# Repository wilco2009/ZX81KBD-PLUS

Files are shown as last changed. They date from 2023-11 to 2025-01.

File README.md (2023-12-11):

# ZX81KBD-PLUS
 Joystick, PS2 & USB keyboard interface for the ZX81
 
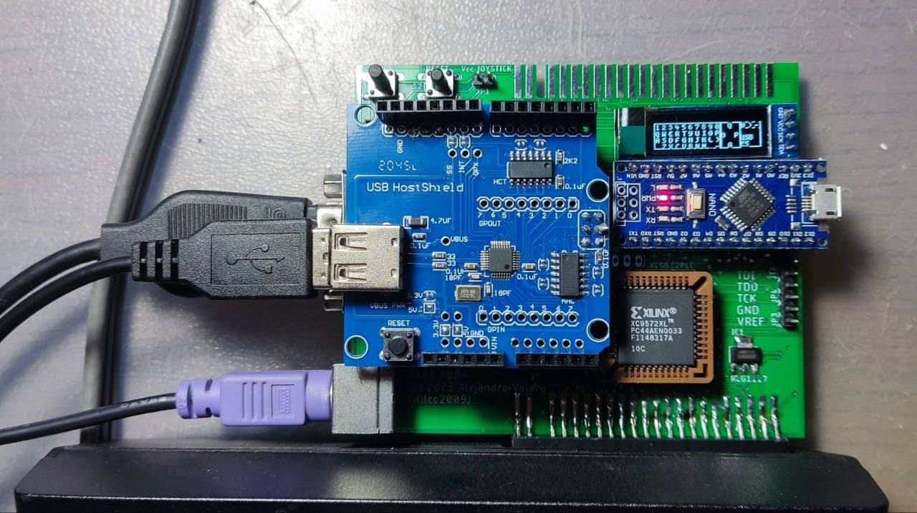
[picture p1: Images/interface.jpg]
 
 
 ## INTERFACE COMPONENTS
 
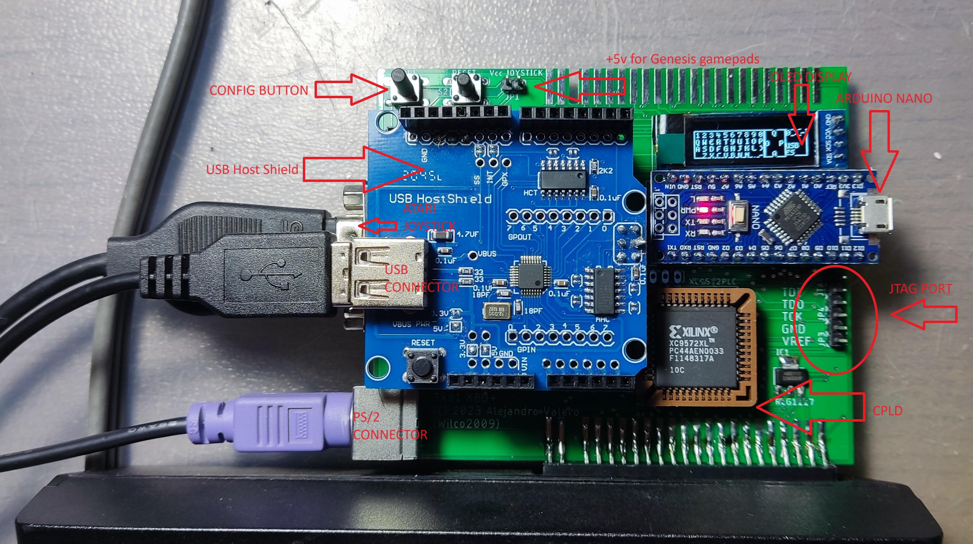
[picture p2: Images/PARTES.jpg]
 

 COMPONENT LIST
 |  Component |  Quantity |
 | ------| --------| 
 | Arduino nano R3	1
 | Push Button 6x6 | 2
 | DB9 male	| 1
 | Mini DIN	9 PIN | 1
 | PCF8574P	| 1
 | USB Host Shield	| 1
 | OLED 128x32 I2C	| 1
 | XC9572XL-PLCC44	| 1
 | LM1117 3v3 regulator SOT223| 1
 | Res 100K	| 2
 | Res 4K7	| 8
 | DIP16 socket	| 1
 | PLCC44 socket (Though hole)	| 1
 | pin header male 1x40 | 1
 | pin header male 1x40 (long pins)	| 1
 | pin header female 1x40	| 2
 | 74AHC125D SOP14	| 1
 | EDGE CONNECTOR | 1
 
Once the interface is assembled, the first thing we have to do is program the arduino (using the arduino IDE) or the avrdude.
We must also program the CPLD using the Xilinx IMPACT program and connecting a programming cable to the JTAG connector.

## REPLACING THE USB HOST SHIELD CHIP
Unless we buy an original USB Host Shield from the official Arduino store, it is very likely that we will end up with a defective board from Aliexpress. The Chinese manufacturers have not strictly followed the original scheme and have used a 74HC125D instead of a 74AHC125D indicated in the original scheme.

The good news is that by replacing this chip it is very likely that we will have a fully functional board, the bad news is that we will have to desolder the old chip and solder the new one.
In the photo you can see the chip that needs to be replaced.

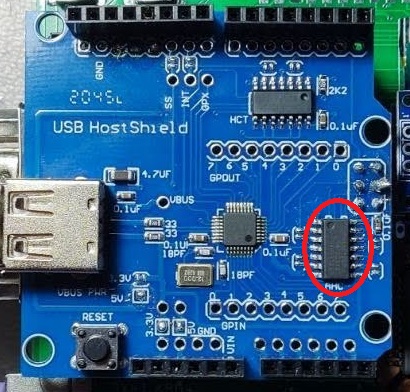
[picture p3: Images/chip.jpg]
 

## MAIN SCREEN

The main screen of the OLED display is divided into two sections.
On the left we have a representation of the zx81 keyboard, and on the right a representation of the joystick with its three buttons (A B and FIRE)
When you press any key on the keyboard or any button on the joystick we will see the pressure on the display.
Additionally, in the joystick section we can see which keys are configured for each of the joystick buttons.

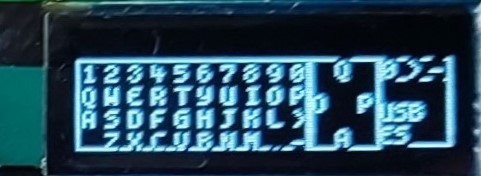
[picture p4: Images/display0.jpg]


## INTERFACE CONFIGURATION

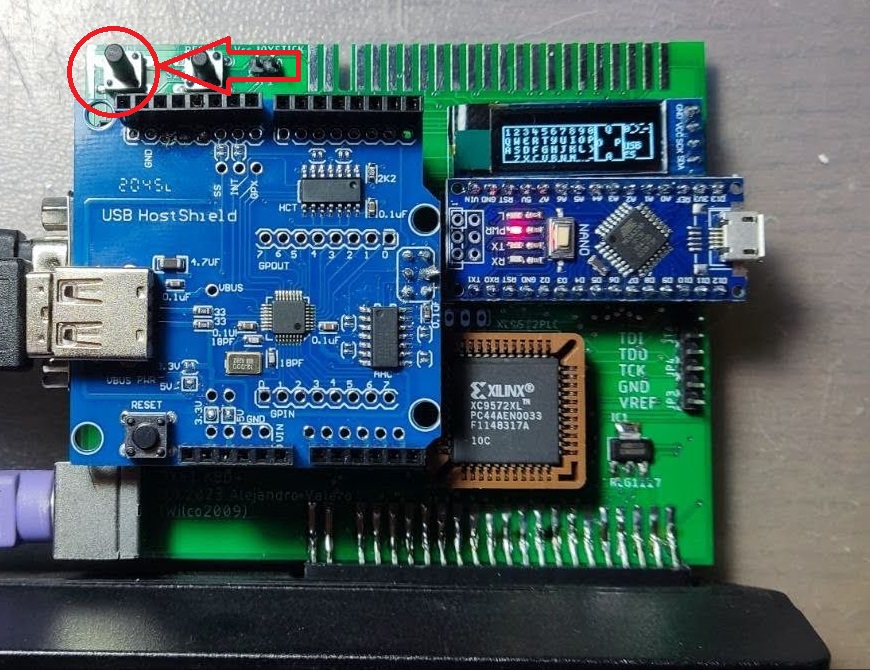
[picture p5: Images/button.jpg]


To enter the configuration menu we can do it in two ways:
- Pressing the configuration button
- Pressing F10 on the keyboard

Once inside the menu we can move through the options using the joystick or the keyboard cursor arrows. 
To select an option we will press the fire button on the joystick or the enter key on the keyboard.

### SELECTION OF KEYBOARD LAYOUT

The first option that appears when we access the menu is the one that will allow us to choose the keyboard layout.

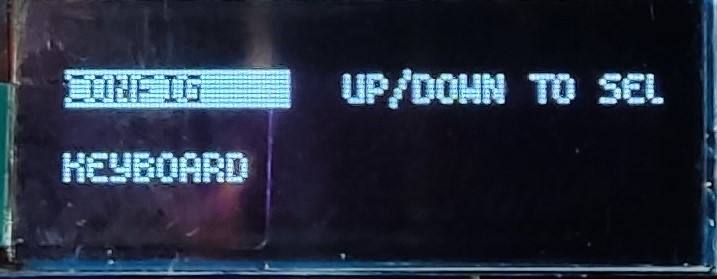
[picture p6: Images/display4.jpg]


The system is prepared for the following distributions:
- "US" - USA
- "UK" - United Kingdom
- "ES" - Spain
- "DE" - Germany

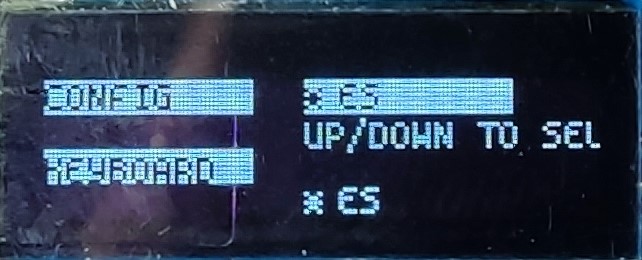
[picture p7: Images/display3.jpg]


The active keyboard will be marked with an asterisk.
We can change the active keyboard with the up/down arrows on the keyboard or joystick and select with enter or the fire button.
The ESC key will return to the main menu.

### REDEFINING JOYSTICK KEYS

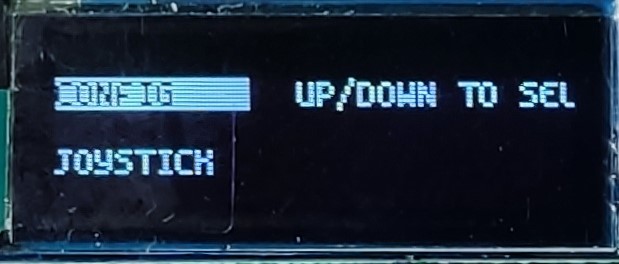
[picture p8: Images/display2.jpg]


To redefine the joystick keys we will select the second option from the main menu by moving down with the arrow and press enter/fire.
After this, a screen identical to the main screen will appear but with the first joystick button to be redefined (UP) flashing.
We will select the key we want with the arrows in the left section of the screen and press ENTER or fire.
We can also directly press the key that we want to assign, except in the case of the cursor and enter keys, which would have to be selected by the first method mentioned.
By pressing the ESC or A key on the joystick we will go to the next button without modifying the current one.

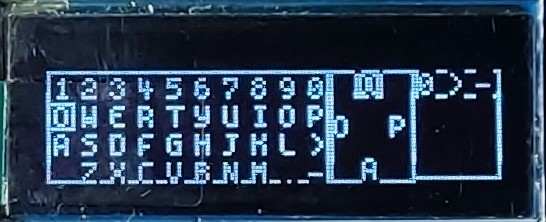
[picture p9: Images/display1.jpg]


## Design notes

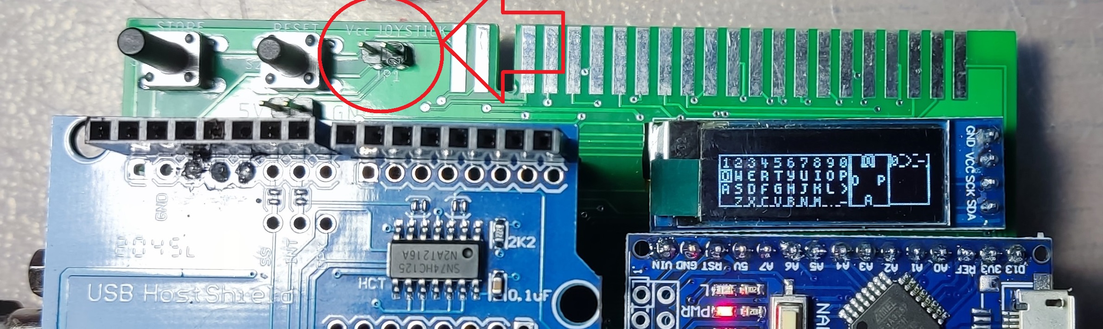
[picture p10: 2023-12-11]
Images/jumper.jpg

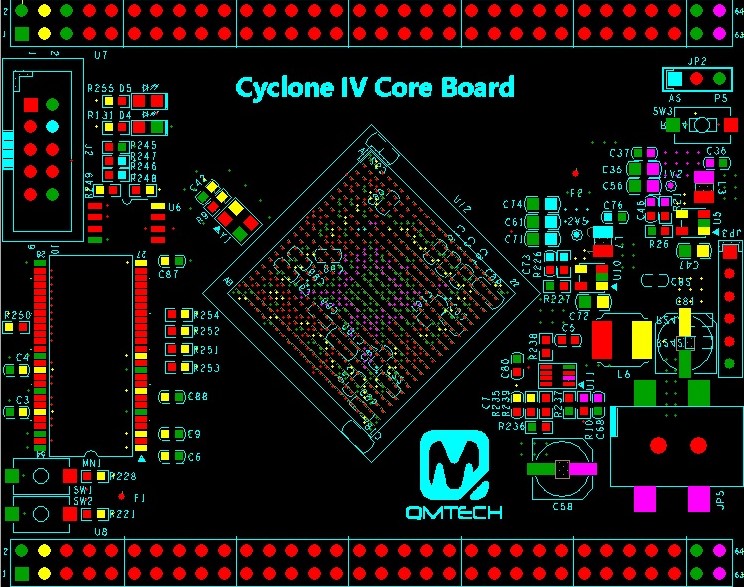
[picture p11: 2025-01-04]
Images/Dimension_V2.jpg

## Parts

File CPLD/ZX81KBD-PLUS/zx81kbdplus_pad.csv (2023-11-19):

Release 8.1i - Fit P.20131013
Copyright(c) 1995-2003 Xilinx Inc. All rights reserved
11-11-2023 1:36AM
NOTE: This file is designed to be imported into a spreadsheet program
such as Microsoft Excel for viewing | printing and sorting. The comma ' | '
character is used as the data field separator.
This file is also designed to support parsing.
Input file: zx81kbdplus.ngd
output file: zx81kbdplus_pad.csv
Part type: xc9572xl
Speed grade: -10
Package: pc44
Pinout by Pin Number:
----- | ----- | ----- | ----- | ----- | ----- | ----- | ----- | ----- | -----
Pin Number | Signal Name | Pin Usage | Pin Name | Direction | IO Standard | IO Bank Number | {blank} | Slew Rate | Termination | {blank} | Voltage | Constraint
P1 | C<0> | I | I/O | INPUT
P2 | CLK | I | I/O | INPUT
P3 | RST | I | I/O | INPUT
P4 | TIE |  | I/O
P5 | TIE |  | I/O/GCK1
P6 | TIE |  | I/O/GCK2
P7 | TIE |  | I/O/GCK3
P8 | TIE |  | I/O
P9 | TIE |  | I/O
P10 | GND |  | GND
P11 | TEST1 | O | I/O | OUTPUT
P12 | TEST2 | O | I/O | OUTPUT
P13 | TEST3 | O | I/O | OUTPUT
P14 | D<0> | O | I/O | OUTPUT
P15 | TDI |  | TDI
P16 | TMS |  | TMS
P17 | TCK |  | TCK
P18 | D<1> | O | I/O | OUTPUT
P19 | D<2> | O | I/O | OUTPUT
P20 | TIE |  | I/O
P21 | VCC |  | VCCINT
P22 | A0 | I | I/O | INPUT
P23 | GND |  | GND
P24 | TIE |  | I/O
P25 | D<3> | O | I/O | OUTPUT
P26 | D<4> | O | I/O | OUTPUT
P27 | A<15> | I | I/O | INPUT
P28 | A<14> | I | I/O | INPUT
P29 | A<13> | I | I/O | INPUT
P30 | TDO |  | TDO
P31 | GND |  | GND
P32 | VCC |  | VCCIO
P33 | A<12> | I | I/O | INPUT
P34 | nIORQ | I | I/O | INPUT
P35 | A<11> | I | I/O | INPUT
P36 | nRD | I | I/O | INPUT
P37 | A<10> | I | I/O | INPUT
P38 | A<9> | I | I/O | INPUT
P39 | A<8> | I | I/O/GSR | INPUT
P40 | C<4> | I | I/O/GTS2 | INPUT
P41 | VCC |  | VCCINT
P42 | C<3> | I | I/O/GTS1 | INPUT
P43 | C<2> | I | I/O | INPUT
P44 | C<1> | I | I/O | INPUT
To preserve the pinout above for future design iterations in
Project Navigator simply execute the (Lock Pins) process
located under the (Implement Design) process in a toolbox named
(Optional Implementation Tools) or invoke PIN2UCF from the
command line. The location constraints will be written into your
specified UCF file

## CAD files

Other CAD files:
CPLD/ZX81KBD-PLUS/isim/zx81kbdtb_isim_beh.exe.sim/work/zx81kbdtb_isim_beh.exe_main.nt.obj
CPLD/ZX81KBD-PLUS/isim/zx81kbdtb_isim_beh.exe.sim/work/m_00000000002093604177_0389357912.nt.obj
CPLD/ZX81KBD-PLUS/isim/zx81kbdtb_isim_beh.exe.sim/work/m_00000000002113335398_0986573990.nt.obj
CPLD/ZX81KBD-PLUS/isim/zx81kbdtb_isim_beh.exe.sim/work/m_00000000004134447467_2073120511.nt.obj

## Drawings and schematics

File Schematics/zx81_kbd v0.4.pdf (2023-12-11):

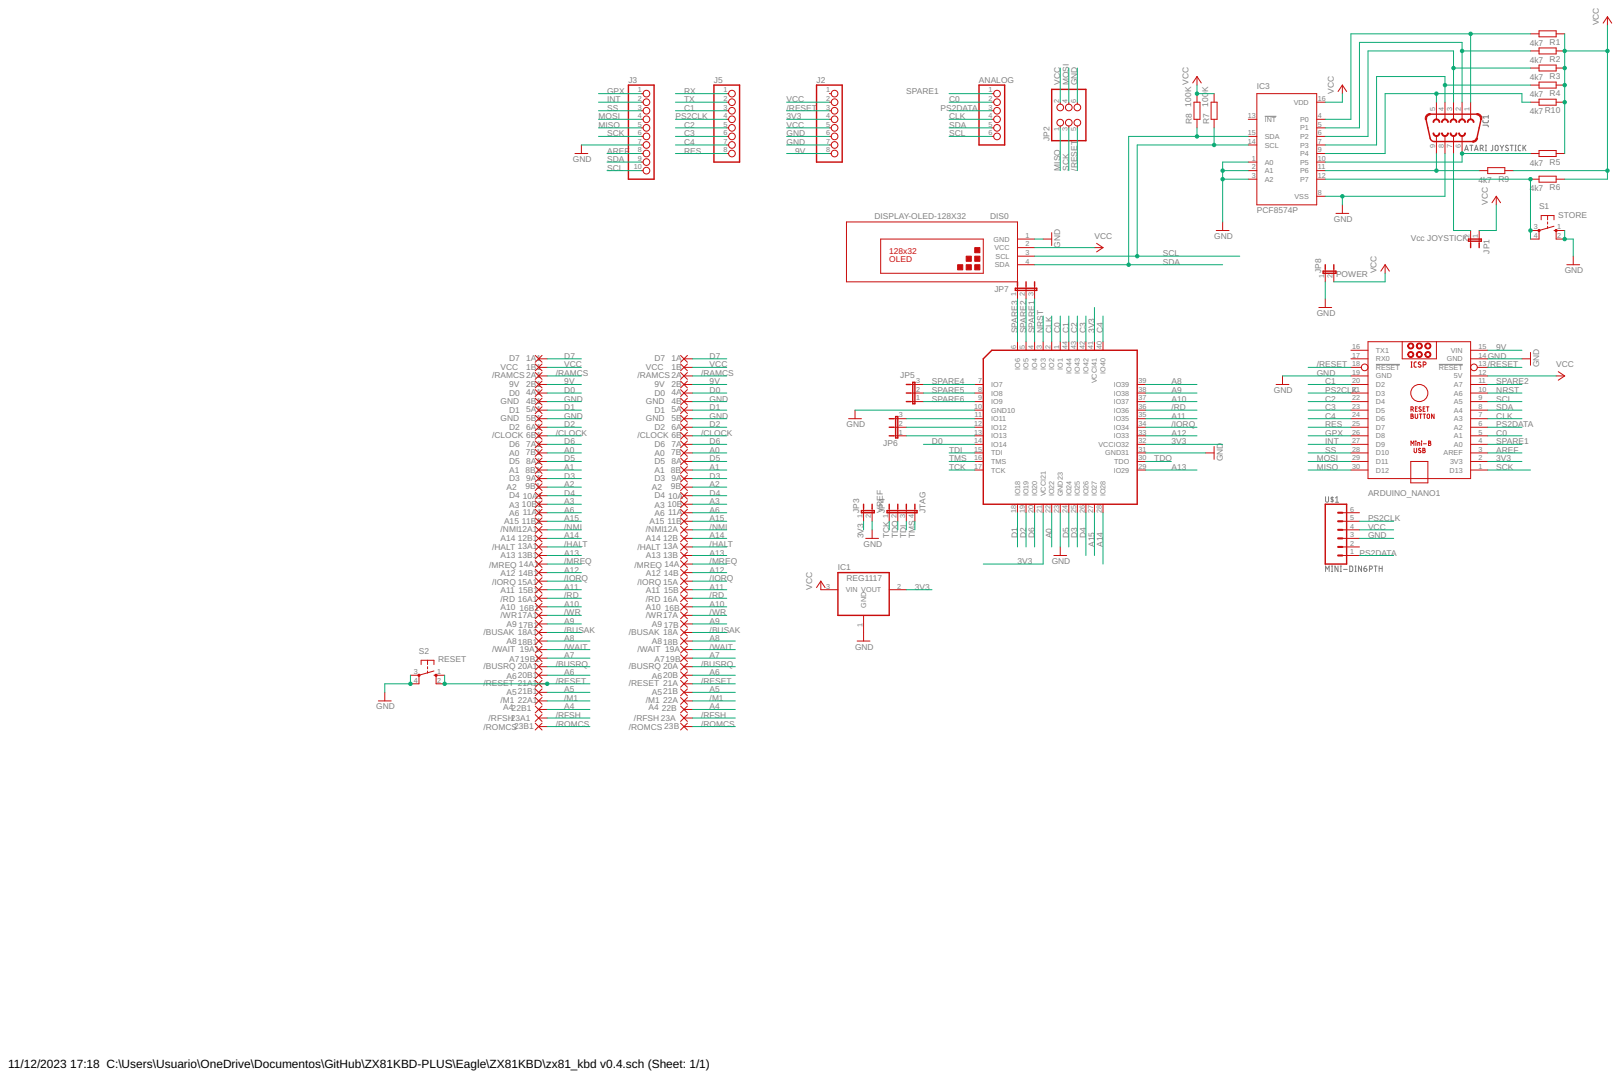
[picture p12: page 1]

11/12/2023 17:18 C:\Users\Usuario\OneDrive\Documentos\GitHub\ZX81KBD-PLUS\Eagle\ZX81KBD\zx81_kbd v0.4.sch (Sheet: 1/1)

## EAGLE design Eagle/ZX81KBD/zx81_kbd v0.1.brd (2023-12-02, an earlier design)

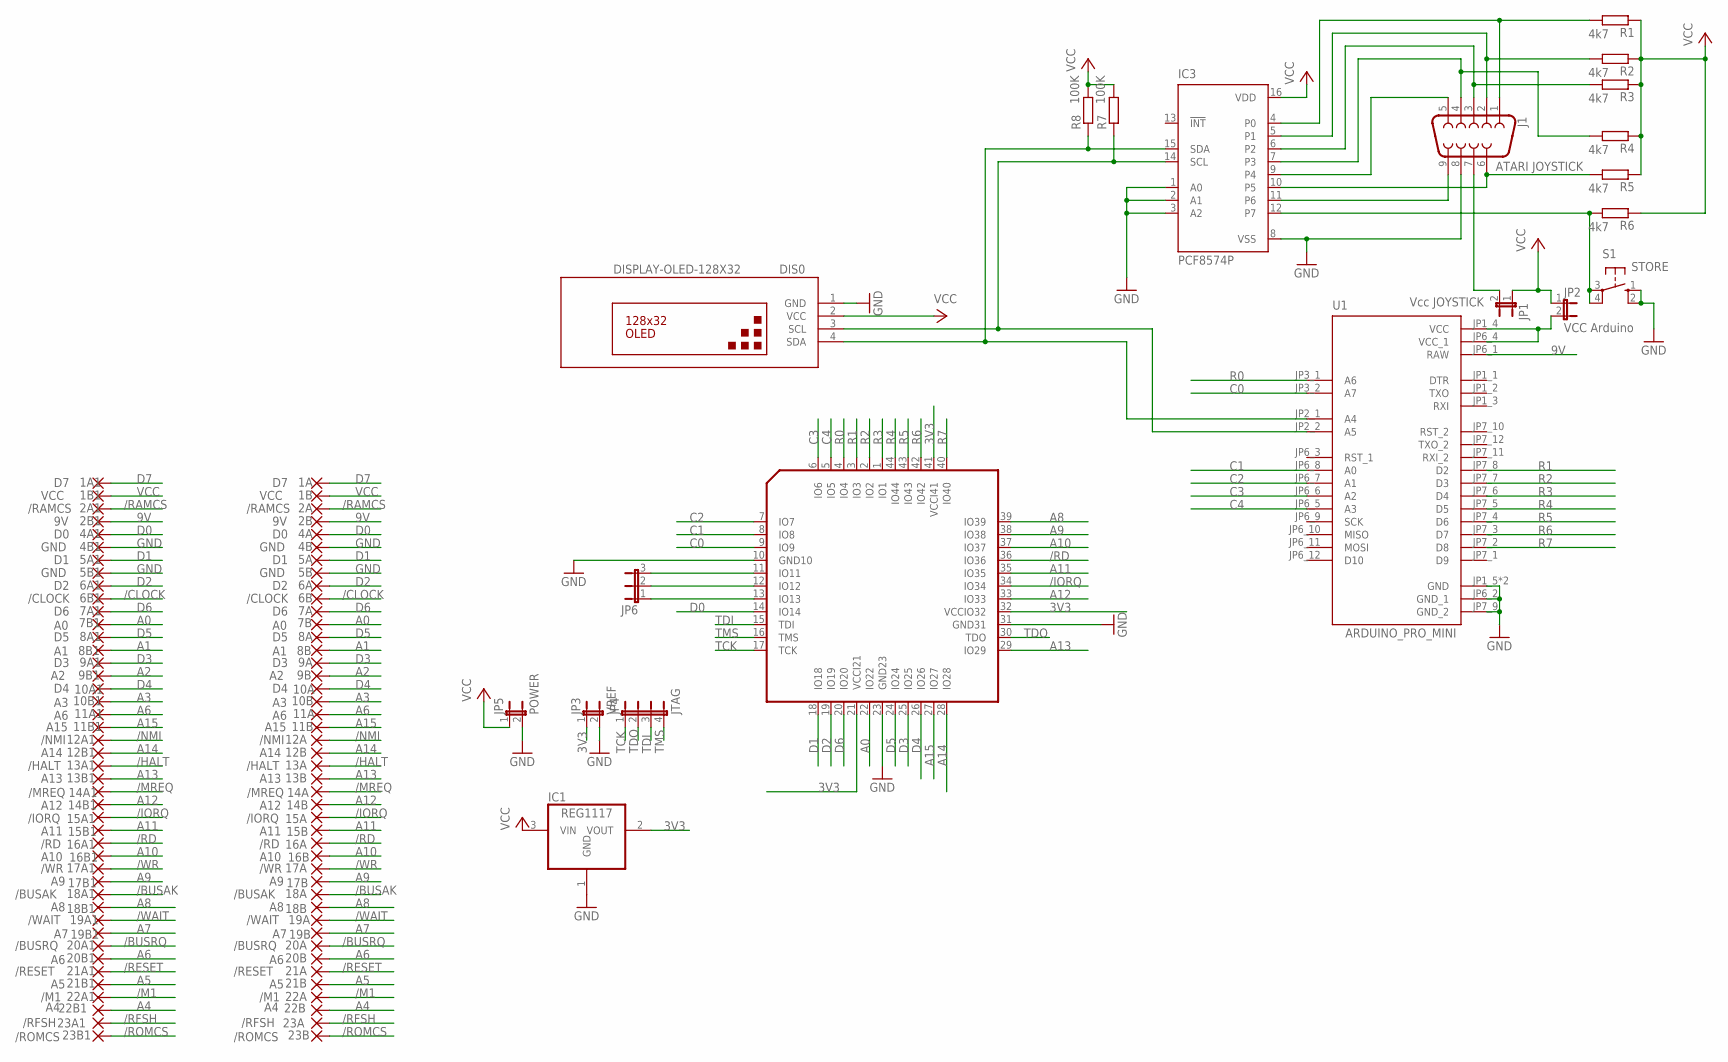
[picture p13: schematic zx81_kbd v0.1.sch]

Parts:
1A, 1A1: D7; EDGEPIN
1B, 1B1: VCC; EDGEPIN
2A, 2A1: /RAMCS; EDGEPIN
2B, 2B1: 9V; EDGEPIN
4A, 4A1: D0; EDGEPIN
4B, 4B1, 5B, 5B1: GND; EDGEPIN
5A, 5A1: D1; EDGEPIN
6A, 6A1: D2; EDGEPIN
6B, 6B1: /CLOCK; EDGEPIN
7A, 7A1: D6; EDGEPIN
7B, 7B1: A0; EDGEPIN
8A, 8A1: D5; EDGEPIN
8B, 8B1: A1; EDGEPIN
9A, 9A1: D3; EDGEPIN
9B, 9B1: A2; EDGEPIN
10A, 10A1: D4; EDGEPIN
10B, 10B1: A3; EDGEPIN
11A, 11A1, 20B, 20B1: A6; EDGEPIN
11B, 11B1: A15; EDGEPIN
12A, 12A1: /NMI; EDGEPIN
12B, 12B1: A14; EDGEPIN
13A, 13A1: /HALT; EDGEPIN
13B, 13B1: A13; EDGEPIN
14A, 14A1: /MREQ; EDGEPIN
14B, 14B1: A12; EDGEPIN
15A, 15A1: /IORQ; EDGEPIN
15B, 15B1: A11; EDGEPIN
16A, 16A1: /RD; EDGEPIN
16B, 16B1: A10; EDGEPIN
17A, 17A1: /WR; EDGEPIN
17B, 17B1: A9; EDGEPIN
18A, 18A1: /BUSAK; EDGEPIN
18B, 18B1: A8; EDGEPIN
19A, 19A1: /WAIT; EDGEPIN
19B, 19B1: A7; EDGEPIN
20A, 20A1: /BUSRQ; EDGEPIN
21A, 21A1: /RESET; EDGEPIN
21B, 21B1: A5; EDGEPIN
22A, 22A1: /M1; EDGEPIN
22B, 22B1: A4; EDGEPIN
23A, 23A1: /RFSH; EDGEPIN
23B, 23B1: /ROMCS; EDGEPIN
DIS0: DISPLAY-OLED-128X32
IC1: REG1117; SOT223
IC3: PCF8574P; DIL16
J1: ATARI JOYSTICK; DB9_MALE
JP1: Vcc JOYSTICK; JP1
JP2: VCC Arduino; JP1
JP3: VREF; JP1
JP4: JTAG; JP4
JP5: POWER; JP1
JP6: JP2E; JP2
R1, R2, R3, R4, R5, R6: 4k7; 0204/7
R7, R8: 100K; 0204/7
S1: STORE; B3F-10XX_11MM
U1: ARDUINO_PRO_MINI; MODULE_ARDUINO_PRO_MINI
XC95CPLD: XC9572PLC; 3M44

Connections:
3V3: IC1.2 (VOUT), JP3.1, XC95CPLD.21 (VCCI21), XC95CPLD.32 (VCCIO32), XC95CPLD.41 (VCCI41)
9V: 2B.1, 2B1.1, U1.JP6_1 (RAW)
/BUSAK: 18A.1, 18A1.1
/BUSRQ: 20A.1, 20A1.1
/CLOCK: 6B.1, 6B1.1
/HALT: 13A.1, 13A1.1
/IORQ: 15A.1, 15A1.1, XC95CPLD.34 (IO34)
/M1: 22A.1, 22A1.1
/MREQ: 14A.1, 14A1.1
/NMI: 12A.1, 12A1.1
/RAMCS: 2A.1, 2A1.1
/RD: 16A.1, 16A1.1, XC95CPLD.36 (IO36)
/RESET: 21A.1, 21A1.1
/RFSH: 23A.1, 23A1.1
/ROMCS: 23B.1, 23B1.1
/WAIT: 19A.1, 19A1.1
/WR: 17A.1, 17A1.1
A0: 7B.1, 7B1.1, XC95CPLD.22 (IO22)
A1: 8B.1, 8B1.1
A2: 9B.1, 9B1.1
A3: 10B.1, 10B1.1
A4: 22B.1, 22B1.1
A5: 21B.1, 21B1.1
A6: 11A.1, 11A1.1, 20B.1, 20B1.1
A7: 19B.1, 19B1.1
A8: 18B.1, 18B1.1, XC95CPLD.39 (IO39)
A9: 17B.1, 17B1.1, XC95CPLD.38 (IO38)
A10: 16B.1, 16B1.1, XC95CPLD.37 (IO37)
A11: 15B.1, 15B1.1, XC95CPLD.35 (IO35)
A12: 14B.1, 14B1.1, XC95CPLD.33 (IO33)
A13: 13B.1, 13B1.1, XC95CPLD.29 (IO29)
A14: 12B.1, 12B1.1, XC95CPLD.28 (IO28)
A15: 11B.1, 11B1.1, XC95CPLD.27 (IO27)
C0: U1.JP3_2 (A7), XC95CPLD.9 (IO9)
C1: U1.JP6_8 (A0), XC95CPLD.8 (IO8)
C2: U1.JP6_7 (A1), XC95CPLD.7 (IO7)
C3: U1.JP6_6 (A2), XC95CPLD.6 (IO6)
C4: U1.JP6_5 (A3), XC95CPLD.5 (IO5)
D0: 4A.1, 4A1.1, XC95CPLD.14 (IO14)
D1: 5A.1, 5A1.1, XC95CPLD.18 (IO18)
D2: 6A.1, 6A1.1, XC95CPLD.19 (IO19)
D3: 9A.1, 9A1.1, XC95CPLD.25 (IO25)
D4: 10A.1, 10A1.1, XC95CPLD.26 (IO26)
D5: 8A.1, 8A1.1, XC95CPLD.24 (IO24)
D6: 7A.1, 7A1.1, XC95CPLD.20 (IO20)
D7: 1A.1, 1A1.1
GND: 4B.1, 4B1.1, 5B.1, 5B1.1, DIS0.1 (GND), IC1.1 (GND), IC3.1 (A0), IC3.2 (A1), IC3.3 (A2), IC3.8 (VSS), J1.8, JP3.2, JP5.2, S1.1 (S), S1.2 (S1), U1.JP1_5 (GND), U1.JP1_6 (GND), U1.JP6_2 (GND_1), U1.JP7_9 (GND_2), XC95CPLD.10 (GND10), XC95CPLD.23 (GND23), XC95CPLD.31 (GND31)
unnamed: JP6.3, XC95CPLD.11 (IO11)
unnamed: JP6.2, XC95CPLD.12 (IO12)
unnamed: JP6.1, XC95CPLD.13 (IO13)
unnamed: JP2.2, U1.JP1_4 (VCC), U1.JP6_4 (VCC_1)
unnamed: DIS0.4 (SDA), IC3.15 (SDA), R8.1, U1.JP2_1 (A4)
unnamed: DIS0.3 (SCL), IC3.14 (SCL), R7.1, U1.JP2_2 (A5)
unnamed: IC3.4 (P0), J1.1, R1.2
unnamed: IC3.5 (P1), J1.2, R2.2
unnamed: IC3.6 (P2), J1.3, R3.2
unnamed: IC3.7 (P3), J1.4, R4.2
unnamed: IC3.10 (P5), J1.6, R5.2
unnamed: IC3.9 (P4), J1.5
unnamed: IC3.12 (P7), R6.2, S1.3, S1.4 (P1)
unnamed: J1.7, JP1.2
unnamed: IC3.11 (P6), J1.9
R0: U1.JP3_1 (A6), XC95CPLD.4 (IO4)
R1: U1.JP7_8 (D2), XC95CPLD.3 (IO3)
R2: U1.JP7_7 (D3), XC95CPLD.2 (IO2)
R3: U1.JP7_6 (D4), XC95CPLD.1 (IO1)
R4: U1.JP7_5 (D5), XC95CPLD.44 (IO44)
R5: U1.JP7_4 (D6), XC95CPLD.43 (IO43)
R6: U1.JP7_3 (D7), XC95CPLD.42 (IO42)
R7: U1.JP7_2 (D8), XC95CPLD.40 (IO40)
TCK: JP4.1, XC95CPLD.17 (TCK)
TDI: JP4.3, XC95CPLD.15 (TDI)
TDO: JP4.2, XC95CPLD.30 (TDO)
TMS: JP4.4, XC95CPLD.16 (TMS)
VCC: 1B.1, 1B1.1, DIS0.2 (VCC), IC1.3 (VIN), IC3.16 (VDD), JP1.1, JP2.1, JP5.1, R1.1, R2.1, R3.1, R4.1, R5.1, R6.1, R7.2, R8.2

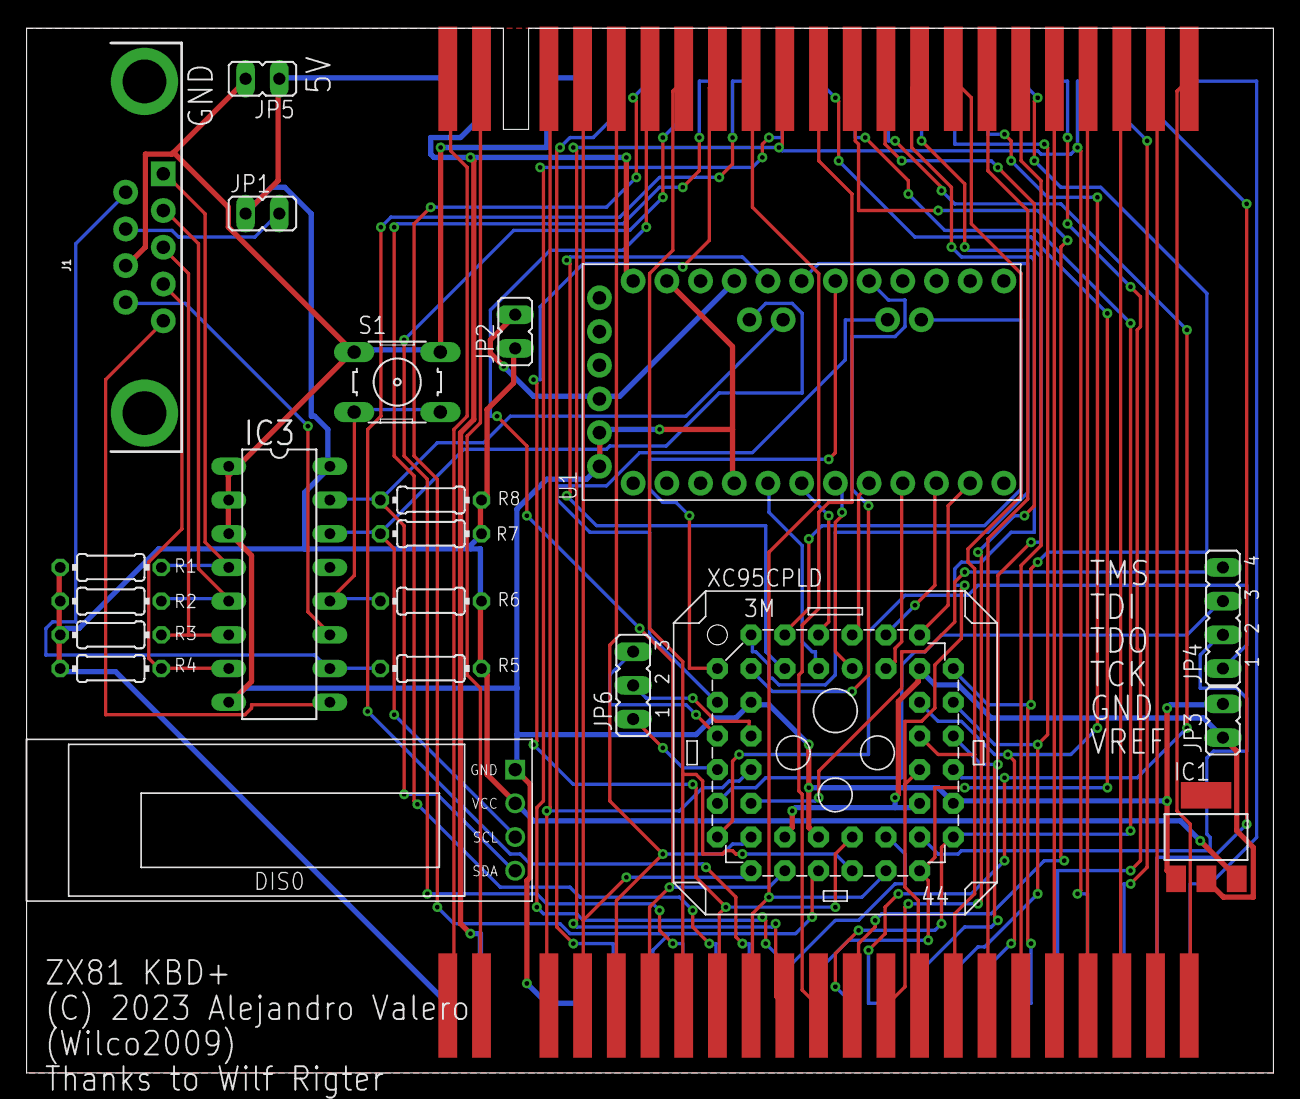
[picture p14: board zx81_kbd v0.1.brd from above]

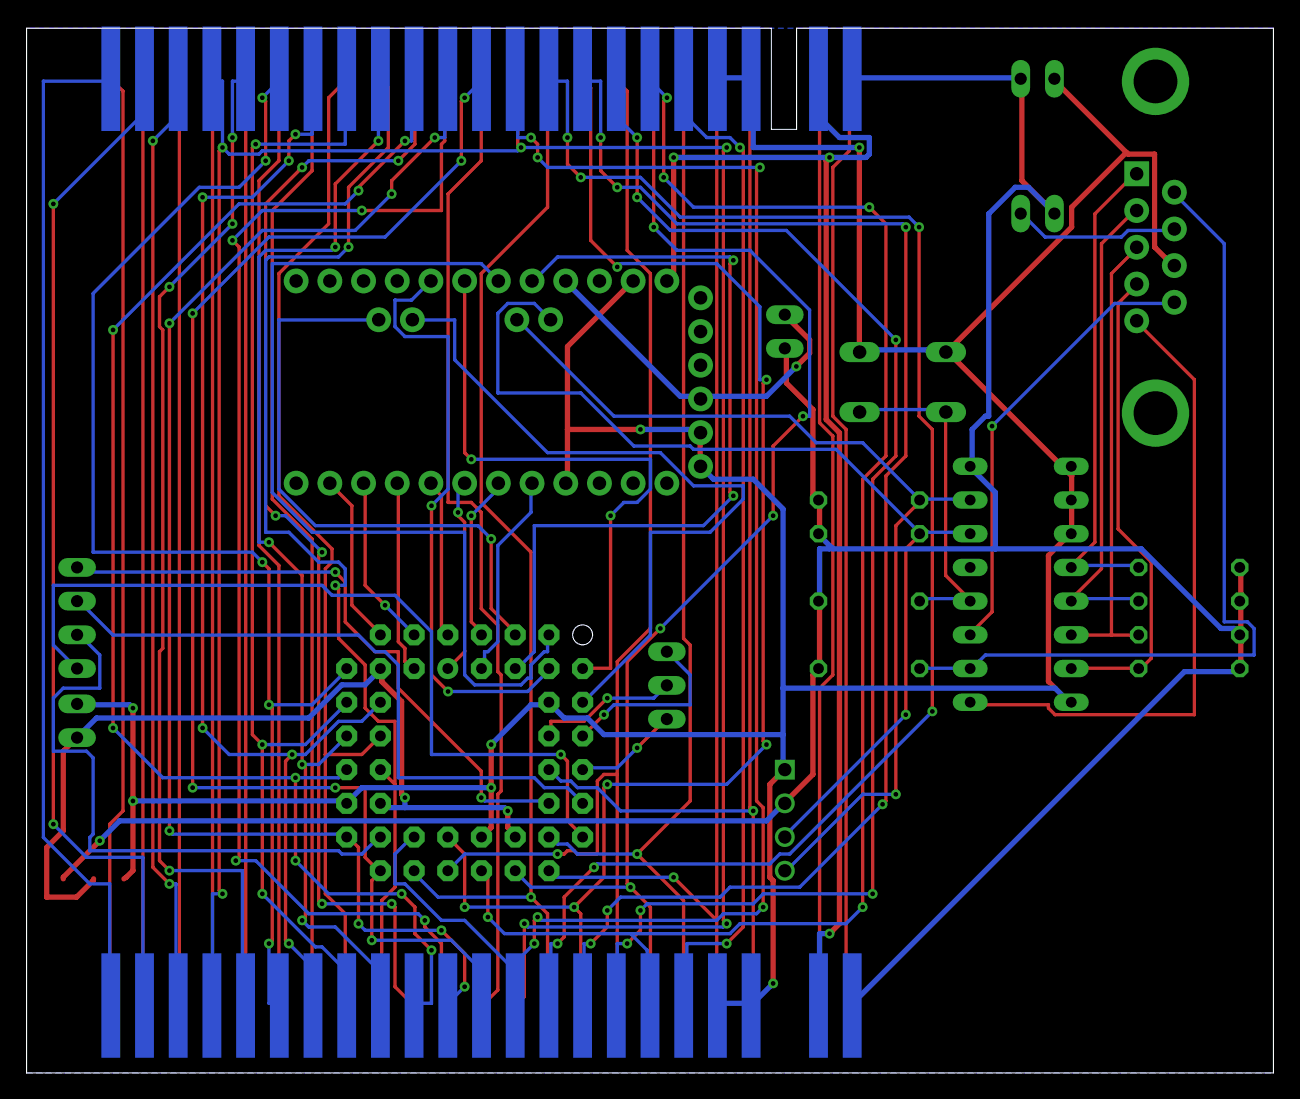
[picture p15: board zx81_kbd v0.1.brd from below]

Board: 2 copper layers, 94.0 x 78.7 mm, 109 parts (44 on the bottom side), 75 nets.

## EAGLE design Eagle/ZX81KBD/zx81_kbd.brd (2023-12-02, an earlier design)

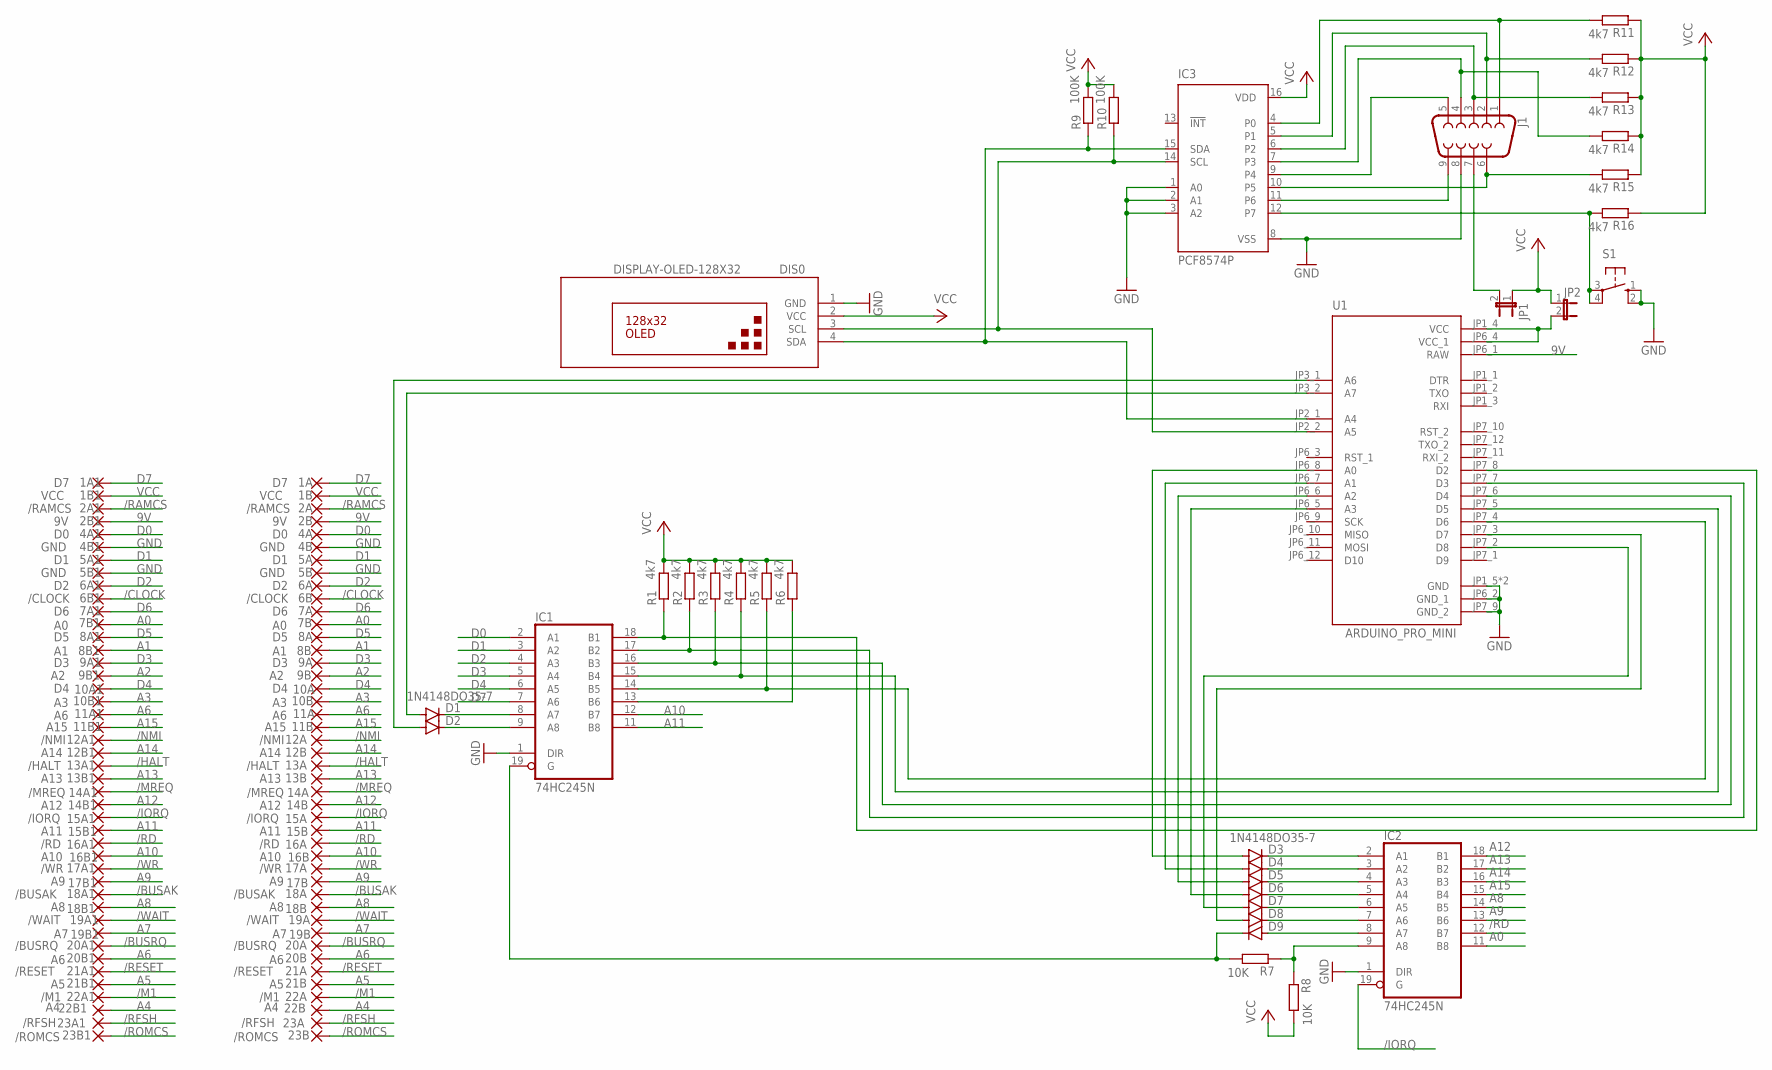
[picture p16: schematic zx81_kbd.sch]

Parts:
1A, 1A1: D7; EDGEPIN
1B, 1B1: VCC; EDGEPIN
2A, 2A1: /RAMCS; EDGEPIN
2B, 2B1: 9V; EDGEPIN
4A, 4A1: D0; EDGEPIN
4B, 4B1, 5B, 5B1: GND; EDGEPIN
5A, 5A1: D1; EDGEPIN
6A, 6A1: D2; EDGEPIN
6B, 6B1: /CLOCK; EDGEPIN
7A, 7A1: D6; EDGEPIN
7B, 7B1: A0; EDGEPIN
8A, 8A1: D5; EDGEPIN
8B, 8B1: A1; EDGEPIN
9A, 9A1: D3; EDGEPIN
9B, 9B1: A2; EDGEPIN
10A, 10A1: D4; EDGEPIN
10B, 10B1: A3; EDGEPIN
11A, 11A1, 20B, 20B1: A6; EDGEPIN
11B, 11B1: A15; EDGEPIN
12A, 12A1: /NMI; EDGEPIN
12B, 12B1: A14; EDGEPIN
13A, 13A1: /HALT; EDGEPIN
13B, 13B1: A13; EDGEPIN
14A, 14A1: /MREQ; EDGEPIN
14B, 14B1: A12; EDGEPIN
15A, 15A1: /IORQ; EDGEPIN
15B, 15B1: A11; EDGEPIN
16A, 16A1: /RD; EDGEPIN
16B, 16B1: A10; EDGEPIN
17A, 17A1: /WR; EDGEPIN
17B, 17B1: A9; EDGEPIN
18A, 18A1: /BUSAK; EDGEPIN
18B, 18B1: A8; EDGEPIN
19A, 19A1: /WAIT; EDGEPIN
19B, 19B1: A7; EDGEPIN
20A, 20A1: /BUSRQ; EDGEPIN
21A, 21A1: /RESET; EDGEPIN
21B, 21B1: A5; EDGEPIN
22A, 22A1: /M1; EDGEPIN
22B, 22B1: A4; EDGEPIN
23A, 23A1: /RFSH; EDGEPIN
23B, 23B1: /ROMCS; EDGEPIN
D1, D2, D3, D4, D5, D6, D7, D8, D9: 1N4148DO35-7; DO35-7
DIS0: DISPLAY-OLED-128X32
IC1, IC2: 74HC245N; DIL20
IC3: PCF8574P; DIL16
J1: DB9MALE; DB9_MALE
JP1, JP2: JP1E; JP1
R1, R2, R3, R4, R5, R6, R11, R12, R13, R14, R15, R16: 4k7; 0204/7
R7, R8: 10K; 0204/7
R9, R10: 100K; 0204/7
S1: 10-XX11MM; B3F-10XX_11MM
U1: ARDUINO_PRO_MINI; MODULE_ARDUINO_PRO_MINI

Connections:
9V: 2B.1, 2B1.1, U1.JP6_1 (RAW)
/BUSAK: 18A.1, 18A1.1
/BUSRQ: 20A.1, 20A1.1
/CLOCK: 6B.1, 6B1.1
/HALT: 13A.1, 13A1.1
/IORQ: 15A.1, 15A1.1, IC2.19 (G)
/M1: 22A.1, 22A1.1
/MREQ: 14A.1, 14A1.1
/NMI: 12A.1, 12A1.1
/RAMCS: 2A.1, 2A1.1
/RD: 16A.1, 16A1.1, IC2.12 (B7)
/RESET: 21A.1, 21A1.1
/RFSH: 23A.1, 23A1.1
/ROMCS: 23B.1, 23B1.1
/WAIT: 19A.1, 19A1.1
/WR: 17A.1, 17A1.1
A0: 7B.1, 7B1.1, IC2.11 (B8)
A1: 8B.1, 8B1.1
A2: 9B.1, 9B1.1
A3: 10B.1, 10B1.1
A4: 22B.1, 22B1.1
A5: 21B.1, 21B1.1
A6: 11A.1, 11A1.1, 20B.1, 20B1.1
A7: 19B.1, 19B1.1
A8: 18B.1, 18B1.1, IC2.14 (B5)
A9: 17B.1, 17B1.1, IC2.13 (B6)
A10: 16B.1, 16B1.1, IC1.12 (B7)
A11: 15B.1, 15B1.1, IC1.11 (B8)
A12: 14B.1, 14B1.1, IC2.18 (B1)
A13: 13B.1, 13B1.1, IC2.17 (B2)
A14: 12B.1, 12B1.1, IC2.16 (B3)
A15: 11B.1, 11B1.1, IC2.15 (B4)
D0: 4A.1, 4A1.1, IC1.2 (A1)
D1: 5A.1, 5A1.1, IC1.3 (A2)
D2: 6A.1, 6A1.1, IC1.4 (A3)
D3: 9A.1, 9A1.1, IC1.5 (A4)
D4: 10A.1, 10A1.1, IC1.6 (A5)
D5: 8A.1, 8A1.1
D6: 7A.1, 7A1.1
D7: 1A.1, 1A1.1, IC1.7 (A6)
GND: 4B.1, 4B1.1, 5B.1, 5B1.1, DIS0.1 (GND), IC1.1 (DIR), IC1.10 (GND), IC2.1 (DIR), IC2.10 (GND), IC3.1 (A0), IC3.2 (A1), IC3.3 (A2), IC3.8 (VSS), J1.8, S1.1 (S), S1.2 (S1), U1.JP1_5 (GND), U1.JP1_6 (GND), U1.JP6_2 (GND_1), U1.JP7_9 (GND_2)
unnamed: D3.C, IC2.2 (A1)
unnamed: IC1.18 (B1), R1.1, U1.JP7_8 (D2)
unnamed: IC1.17 (B2), R2.1, U1.JP7_7 (D3)
unnamed: IC1.16 (B3), R3.1, U1.JP7_6 (D4)
unnamed: JP2.2, U1.JP1_4 (VCC), U1.JP6_4 (VCC_1)
unnamed: IC1.14 (B5), R5.1, U1.JP7_4 (D6)
unnamed: IC1.13 (B6), R6.1
unnamed: D4.C, IC2.3 (A2)
unnamed: D5.C, IC2.4 (A3)
unnamed: D6.C, IC2.5 (A4)
unnamed: D7.C, IC2.6 (A5)
unnamed: D8.C, IC2.7 (A6)
unnamed: D9.A, IC2.8 (A7)
unnamed: IC2.9 (A8), R7.1, R8.1
unnamed: D1.A, U1.JP3_2 (A7)
unnamed: D1.C, IC1.8 (A7)
unnamed: D2.C, IC1.9 (A8)
unnamed: D9.C, IC1.19 (G), R7.2
unnamed: D2.A, U1.JP3_1 (A6)
unnamed: DIS0.4 (SDA), IC3.15 (SDA), R9.1, U1.JP2_1 (A4)
unnamed: DIS0.3 (SCL), IC3.14 (SCL), R10.1, U1.JP2_2 (A5)
unnamed: D6.A, U1.JP6_5 (A3)
unnamed: D5.A, U1.JP6_6 (A2)
unnamed: D4.A, U1.JP6_7 (A1)
unnamed: D7.A, U1.JP7_2 (D8)
unnamed: D8.A, U1.JP7_3 (D7)
unnamed: IC3.4 (P0), J1.1, R11.2
unnamed: IC1.15 (B4), R4.1, U1.JP7_5 (D5)
unnamed: D3.A, U1.JP6_8 (A0)
unnamed: IC3.5 (P1), J1.2, R12.2
unnamed: IC3.6 (P2), J1.3, R13.2
unnamed: IC3.7 (P3), J1.4, R14.2
unnamed: IC3.10 (P5), J1.6, R15.2
unnamed: IC3.9 (P4), J1.5
unnamed: IC3.12 (P7), R16.2, S1.3, S1.4 (P1)
unnamed: J1.7, JP1.2
unnamed: IC3.11 (P6), J1.9
VCC: 1B.1, 1B1.1, DIS0.2 (VCC), IC1.20 (VCC), IC2.20 (VCC), IC3.16 (VDD), JP1.1, JP2.1, R1.2, R2.2, R3.2, R4.2, R5.2, R6.2, R8.2, R9.2, R10.2, R11.1, R12.1, R13.1, R14.1, R15.1, R16.1

Board: 2 copper layers, 122 parts (44 on the bottom side), 79 nets, no tracks yet.

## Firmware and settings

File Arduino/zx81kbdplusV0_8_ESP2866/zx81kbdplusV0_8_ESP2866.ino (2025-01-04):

#if defined(ARDUINO_UNOR4_MINIMA) || defined(ARDUINO_UNOR4_WIFI)
  #define UNOR4
#endif
//#define USBKEYBOARD
#define PS2
//#define USBJOYSTICK
//#define DETECTUSB

#include <Wire.h>
#include <EEPROM.h>
#include <U8g2lib.h>
#ifdef USBKEYBOARD
  #include <hidboot.h>
  //#include <usbhub.h>
#endif
#ifdef USBJOYSTICK
  #include <usbhid.h>
  #include <hiduniversal.h>
#endif
#include <SPI.h>
#ifdef PS2
  #include "PS2Keyboard.h"
#endif

#include "GLOBAL.h"
#include "SCANCODES.h"
#include "INTL.h"
#include "KEYBOARD.h"
#ifdef USBKEYBOARD
  #include "KBDPARSER.h"
#endif
#ifdef USBJOYSTICK
  #include "hidJoystickParser.h"
#endif
#include "MENUS.h"
#include "LOGO.h"

#define RESET   digitalWrite(NRST, 0);  \
                delayMicroseconds(50); \
                /*delay(1);*/               \
                digitalWrite(NRST, 1);  \
                delayMicroseconds(50); \
                /*delay(1);*/               \

 //delayMicroseconds(50);
 #define CLOCK  digitalWrite(CLK, 0);   \
                delayMicroseconds(50); \
                /*delay(1);*/               \
                digitalWrite(CLK, 1);   \
                delayMicroseconds(50); \
                /*delay(1);*/               \

#ifdef USBKEYBOARD
  KbdRptParser Prs;
#endif

#ifdef USBJOYSTICK
  JoystickEvents JoyEvents;
  JoystickReportParser Joy(&JoyEvents);
#endif

#ifdef USBKEYBOARD
  uint8_t rcode;
  uint8_t usbstate;
  uint8_t laststate;
  //uint8_t buf[sizeof(USB_DEVICE_DESCRIPTOR)];
  USB_DEVICE_DESCRIPTOR buf;
#endif

void setup() {
// Wire.begin();
  u8g2.begin();
  #if defined (__XTENSA__)
  EEPROM.begin(EEPROM_SIZE);
  #endif
  Serial.begin(9600);
  Serial.println(F("START"));
  pinMode(CLK,OUTPUT);
  pinMode(NRST,OUTPUT);
  pinMode(C0,OUTPUT);
  pinMode(C1,OUTPUT);
  pinMode(C2,OUTPUT);
  pinMode(C3,OUTPUT);
  pinMode(C4,OUTPUT);
  u8g2.setFont(u8g2_font_ncenB14_tr);
  u8g2.setFont(u8g2_font_smallsimple_tr);
  u8g2.setFont(u8g2_font_spleen5x8_mu);
 u8g2.firstPage();
  do {
    u8g2.drawXBMP(0,0,ZXKBDPLUS_width,ZXKBDPLUS_height,ZXKBDPLUS_bits);
  } while ( u8g2.nextPage() );
  //SJOY[0] = 0;
  memset(rows,0xff,8);
  //for (int i=0;i<=7;i++) rows[i]=0xff;
#ifdef USBKEYBOARD
  if (Usb.Init() == -1)
    Serial.println(F("OSC did not start."));
  else
    Serial.println(F("OSC started."));
#endif

  delay( 1000 );

#ifdef USBKEYBOARD
  HidKeyboard.SetReportParser(0, &Prs);
#endif

#ifdef PS2
  keyboard.begin(DataPin, IRQpin);
  scState = stPRESS;
#endif
  prev_value = 0;

  
  config_ver = EEPROM.read(0);
  switch (config_ver){
    case 1: 
      currentKeyboard = EEPROM.read(1);
      selectIntlKeyboard(currentKeyboard);
      for (int i=0; i<7; i++){
        joyKeys[i] = EEPROM.read(i+2);
      }
      break;
    default:
      break;

  }
}

boolean button_pressed(){
  return CONFIG || F10Pressed;
}

// the loop function runs over and over again forever
void loop() {
#ifdef PS2
  readPS2Keyboard();
#endif
// Leer dato de canal 'channel'
  Wire.requestFrom(pcfAddress, 1 << channel);
  if (Wire.available())
  {
    value = Wire.read();
    if (JUP) pressKey(joyKeys[UP]); else if (PREV_JUP) releaseKey(joyKeys[UP]); 
    if (JDOWN) pressKey(joyKeys[DOWN]); else if (PREV_JDOWN) releaseKey(joyKeys[DOWN]); 
    if (JLEFT) pressKey(joyKeys[LEFT]); else if (PREV_JLEFT) releaseKey(joyKeys[LEFT]); 
    if (JRIGHT) pressKey(joyKeys[RIGHT]); else if (PREV_JRIGHT) releaseKey(joyKeys[RIGHT]); 
    if (JBUTB) pressKey(joyKeys[BUTB]); else if (PREV_JBUTB) releaseKey(joyKeys[BUTB]); 
    if (JTRIGER) pressKey(joyKeys[TRIG]); else if (PREV_JTRIGER) releaseKey(joyKeys[TRIG]);  
    if (JBUTA) pressKey(joyKeys[BUTA]); else if (PREV_JBUTA) releaseKey(joyKeys[BUTA]); 
    prev_value=value;
  }
  Wire.endTransmission();

  // Mostrar el valor por puerto serie
  //Serial.println(rows[5]);
  displayKeyboard(false,0,0,0);  
  //displayJoystick();
  RESET
  //Serial.println(rows[7]);
  for (int i=0; i<=7;i++){
    for (int j=0; j<=4; j++){
        digitalWrite(C[j],bitRead(rows[i],j));
    }
    CLOCK
  }

#ifdef USBKEYBOARD
  Usb.Task();
#endif

  if (button_pressed()) {waitNoKey(); configMenu();}
  #ifdef USBKEYBOARD
  #ifdef DETECTUSB
  usbstate = Usb.getUsbTaskState();
  if(usbstate != laststate) {
    laststate = usbstate;
    switch (usbstate){
      case USB_STATE_RUNNING:
            E_Notify(PSTR("\r\nGetting device descriptor"), 0x80);
            rcode = Usb.getDevDescr(1, 0, sizeof (USB_DEVICE_DESCRIPTOR), (uint8_t*) & buf);

            if(rcode) {
                    E_Notify(PSTR("\r\nError reading device descriptor. Error code "), 0x80);
                    print_hex(rcode, 8);
            } else {
              USB_connected = true;
                /**/
                E_Notify(PSTR("\r\nDescriptor Length:\t"), 0x80);
                print_hex(buf.bLength, 8);
                E_Notify(PSTR("\r\nDescriptor type:\t"), 0x80);
                print_hex(buf.bDescriptorType, 8);
                E_Notify(PSTR("\r\nUSB version:\t\t"), 0x80);
                print_hex(buf.bcdUSB, 16);
                E_Notify(PSTR("\r\nDevice class:\t\t"), 0x80);
                print_hex(buf.bDeviceClass, 8);
                E_Notify(PSTR("\r\nDevice Subclass:\t"), 0x80);
                print_hex(buf.bDeviceSubClass, 8);
                E_Notify(PSTR("\r\nDevice Protocol:\t"), 0x80);
                print_hex(buf.bDeviceProtocol, 8);
                E_Notify(PSTR("\r\nMax.packet size:\t"), 0x80);
                print_hex(buf.bMaxPacketSize0, 8);
                E_Notify(PSTR("\r\nVendor  ID:\t\t"), 0x80);
                print_hex(buf.idVendor, 16);
                E_Notify(PSTR("\r\nProduct ID:\t\t"), 0x80);
                print_hex(buf.idProduct, 16);
                E_Notify(PSTR("\r\nRevision ID:\t\t"), 0x80);
                print_hex(buf.bcdDevice, 16);
                E_Notify(PSTR("\r\nMfg.string index:\t"), 0x80);
                print_hex(buf.iManufacturer, 8);
                E_Notify(PSTR("\r\nProd.string index:\t"), 0x80);
                print_hex(buf.iProduct, 8);
                E_Notify(PSTR("\r\nSerial number index:\t"), 0x80);
                print_hex(buf.iSerialNumber, 8);
                E_Notify(PSTR("\r\nNumber of conf.:\t"), 0x80);
                print_hex(buf.bNumConfigurations, 8);
            }
    }
  }
  #endif
  #endif
}

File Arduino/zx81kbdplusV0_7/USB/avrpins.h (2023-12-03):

/* Copyright (C) 2011 Circuits At Home, LTD. All rights reserved.

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
Contact information
-------------------

Circuits At Home, LTD
Web      :  http://www.circuitsathome.com
e-mail   :  support@circuitsathome.com
 */

/* derived from Konstantin Chizhov's AVR port templates */

#if !defined(_usb_h_) || defined(_avrpins_h_)
#error "Never include avrpins.h directly; include Usb.h instead"
#else
#define _avrpins_h_

#if defined(__AVR__)

// pointers are 16 bits on AVR
#define pgm_read_pointer(p) pgm_read_word(p)

// Support for these boards needs to be manually activated in settings.h or in a makefile
#if !defined(BOARD_MEGA_ADK) && defined(__AVR_ATmega2560__) && (USE_UHS_MEGA_ADK || defined(ARDUINO_AVR_ADK))
#define BOARD_MEGA_ADK
#elif !defined(BOARD_BLACK_WIDDOW) && USE_UHS_BLACK_WIDDOW
#define BOARD_BLACK_WIDDOW
#endif

#ifdef PORTA
#define USE_PORTA
#endif
#ifdef PORTB
#define USE_PORTB
#endif
#ifdef PORTC
#define USE_PORTC
#endif
#ifdef PORTD
#define USE_PORTD
#endif
#ifdef PORTE
#define USE_PORTE
#endif
#ifdef PORTF
#define USE_PORTF
#endif
#ifdef PORTG
#define USE_PORTG
#endif
#ifdef PORTH
#define USE_PORTH
#endif
#ifdef PORTJ
#define USE_PORTJ
#endif
#ifdef PORTK
#define USE_PORTK
#endif
#ifdef PORTL
#define USE_PORTL
#endif
#ifdef PORTQ
#define USE_PORTQ
#endif
#ifdef PORTR
#define USE_PORTR
#endif

#ifdef TCCR0A
#define USE_TCCR0A
#endif
#ifdef TCCR1A
#define USE_TCCR1A
#endif
#ifdef TCCR2A
#define USE_TCCR2A
#endif

//Port definitions for AtTiny, AtMega families.

#define MAKE_PORT(portName, ddrName, pinName, className, ID) \
    class className{\
    public:\
      typedef uint8_t DataT;\
    public:\
      static void Write(DataT value){portName = value;}\
      static void ClearAndSet(DataT clearMask, DataT value){portName = (portName & ~clearMask) | value;}\
      static DataT Read(){return portName;}\
      static void DirWrite(DataT value){ddrName = value;}\
      static DataT DirRead(){return ddrName;}\
      static void Set(DataT value){portName |= value;}\
      static void Clear(DataT value){portName &= ~value;}\
      static void Toggle(DataT value){portName ^= value;}\
      static void DirSet(DataT value){ddrName |= value;}\
      static void DirClear(DataT value){ddrName &= ~value;}\
      static void DirToggle(DataT value){ddrName ^= value;}\
      static DataT PinRead(){return pinName;}\
      enum{Id = ID};\
      enum{Width=sizeof(DataT)*8};\
    };

// TCCR registers to set/clear Arduino PWM
#define MAKE_TCCR(TccrName, className) \
    class className{\
    public:\
      typedef uint8_t DataT;\
    public:\
      static void Write(DataT value){TccrName = value;}\
      static void ClearAndSet(DataT clearMask, DataT value){TccrName = (TccrName & ~clearMask) | value;}\
      static DataT Read(){return TccrName;}\
      static void Set(DataT value){TccrName |= value;}\
      static void Clear(DataT value){TccrName &= ~value;}\
      static void Toggle(DataT value){TccrName ^= value;}\
      enum{Width=sizeof(DataT)*8};\
    };

#ifdef USE_PORTA

MAKE_PORT(PORTA, DDRA, PINA, Porta, 'A')
#endif
#ifdef USE_PORTB
MAKE_PORT(PORTB, DDRB, PINB, Portb, 'B')
#endif
#ifdef USE_PORTC
MAKE_PORT(PORTC, DDRC, PINC, Portc, 'C')
#endif
#ifdef USE_PORTD
MAKE_PORT(PORTD, DDRD, PIND, Portd, 'D')
#endif
#ifdef USE_PORTE
MAKE_PORT(PORTE, DDRE, PINE, Porte, 'E')
#endif
#ifdef USE_PORTF
MAKE_PORT(PORTF, DDRF, PINF, Portf, 'F')
#endif
#ifdef USE_PORTG
MAKE_PORT(PORTG, DDRG, PING, Portg, 'G')
#endif
#ifdef USE_PORTH
MAKE_PORT(PORTH, DDRH, PINH, Porth, 'H')
#endif
#ifdef USE_PORTJ
MAKE_PORT(PORTJ, DDRJ, PINJ, Portj, 'J')
#endif
#ifdef USE_PORTK
MAKE_PORT(PORTK, DDRK, PINK, Portk, 'K')
#endif
#ifdef USE_PORTL
MAKE_PORT(PORTL, DDRL, PINL, Portl, 'L')
#endif
#ifdef USE_PORTQ
MAKE_PORT(PORTQ, DDRQ, PINQ, Portq, 'Q')
#endif
#ifdef USE_PORTR
MAKE_PORT(PORTR, DDRR, PINR, Portr, 'R')
#endif

#ifdef USE_TCCR0A
MAKE_TCCR(TCCR0A, Tccr0a)
#endif
#ifdef USE_TCCR1A
MAKE_TCCR(TCCR1A, Tccr1a)
#endif
#ifdef USE_TCCR2A
MAKE_TCCR(TCCR2A, Tccr2a)
#endif
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

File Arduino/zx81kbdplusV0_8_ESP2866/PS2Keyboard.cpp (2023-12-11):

/*
  PS2Keyboard.cpp - PS2Keyboard library
  Copyright (c) 2007 Free Software Foundation.  All right reserved.
  Written by Christian Weichel <info@32leaves.net>

  ** Mostly rewritten Paul Stoffregen <paul@pjrc.com> 2010, 2011
  ** Modified for use beginning with Arduino 13 by L. Abraham Smith, <n3bah@microcompdesign.com> * 
  ** Modified for easy interrup pin assignement on method begin(datapin,irq_pin). Cuningan <cuninganreset@gmail.com> **

  for more information you can read the original wiki in arduino.cc
  at http://www.arduino.cc/playground/Main/PS2Keyboard
  or http://www.pjrc.com/teensy/td_libs_PS2Keyboard.html

  Version 2.4 (March 2013)
  - Support Teensy 3.0, Arduino Due, Arduino Leonardo & other boards
  - French keyboard layout, David Chochoi, tchoyyfr at yahoo dot fr

  Version 2.3 (October 2011)
  - Minor bugs fixed

  Version 2.2 (August 2011)
  - Support non-US keyboards - thanks to Rainer Bruch for a German keyboard :)

  Version 2.1 (May 2011)
  - timeout to recover from misaligned input
  - compatibility with Arduino "new-extension" branch
  - TODO: send function, proposed by Scott Penrose, scooterda at me dot com

  Version 2.0 (June 2010)
  - Buffering added, many scan codes can be captured without data loss
    if your sketch is busy doing other work
  - Shift keys supported, completely rewritten scan code to ascii
  - Slow linear search replaced with fast indexed table lookups
  - Support for Teensy, Arduino Mega, and Sanguino added

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
  You should have received a copy of the GNU Lesser General Public
  License along with this library; if not, write to the Free Software
  Foundation, Inc., 51 Franklin St, Fifth Floor, Boston, MA  02110-1301  USA
*/

#include "PS2Keyboard.h"

#define BUFFER_SIZE 45
static volatile uint8_t buffer[BUFFER_SIZE];
static volatile uint8_t head, tail;
static uint8_t DataPin;
static uint8_t CharBuffer=0;
static uint8_t UTF8next=0;
static const PS2Keymap_t *keymap=NULL;

// The ISR for the external interrupt
#if defined (__XTENSA__) //ESP8266
ICACHE_RAM_ATTR void ps2interrupt(void)
#else
void ps2interrupt(void)
#endif
{
	static uint8_t bitcount=0;
	static uint8_t incoming=0;
	static uint32_t prev_ms=0;
	uint32_t now_ms;
	uint8_t n, val;

	val = digitalRead(DataPin);
	now_ms = millis();
	if (now_ms - prev_ms > 250) {
		bitcount = 0;
		incoming = 0;
	}
	prev_ms = now_ms;
	n = bitcount - 1;
	if (n <= 7) {
		incoming |= (val << n);
	}
	bitcount++;
	if (bitcount == 11) {
		uint8_t i = head + 1;
		if (i >= BUFFER_SIZE) i = 0;
		if (i != tail) {
			buffer[i] = incoming;
			head = i;
		}
		bitcount = 0;
		incoming = 0;
	}
}

static inline uint8_t get_scan_code(void)
{
	uint8_t c, i;

	i = tail;
	if (i == head) return 0;
	i++;
	if (i >= BUFFER_SIZE) i = 0;
	c = buffer[i];
	tail = i;
	return c;
}

// http://www.quadibloc.com/comp/scan.htm
// http://www.computer-engineering.org/ps2keyboard/scancodes2.html

// These arrays provide a simple key map, to turn scan codes into ISO8859
// output.  If a non-US keyboard is used, these may need to be modified
// for the desired output.
//

const PROGMEM PS2Keymap_t PS2Keymap_US = {
  // without shift
	{0, PS2_F9, 0, PS2_F5, PS2_F3, PS2_F1, PS2_F2, PS2_F12,
	0, PS2_F10, PS2_F8, PS2_F6, PS2_F4, PS2_TAB, '`', 0,
	0, 0 /*Lalt*/, 0 /*Lshift*/, 0, 0 /*Lctrl*/, 'q', '1', 0,
	0, 0, 'z', 's', 'a', 'w', '2', 0,
	0, 'c', 'x', 'd', 'e', '4', '3', 0,
	0, ' ', 'v', 'f', 't', 'r', '5', 0,
	0, 'n', 'b', 'h', 'g', 'y', '6', 0,
	0, 0, 'm', 'j', 'u', '7', '8', 0,
	0, ',', 'k', 'i', 'o', '0', '9', 0,
	0, '.', '/', 'l', ';', 'p', '-', 0,
	0, 0, '\'', 0, '[', '=', 0, 0,
	0 /*CapsLock*/, 0 /*Rshift*/, PS2_ENTER /*Enter*/, ']', 0, '\\', 0, 0,
	0, 0, 0, 0, 0, 0, PS2_BACKSPACE, 0,
	0, '1', 0, '4', '7', 0, 0, 0,
	'0', '.', '2', '5', '6', '8', PS2_ESC, 0 /*NumLock*/,
	PS2_F11, '+', '3', '-', '*', '9', PS2_SCROLL, 0,
	0, 0, 0, PS2_F7 },
  // with shift
	{0, PS2_F9, 0, PS2_F5, PS2_F3, PS2_F1, PS2_F2, PS2_F12,
	0, PS2_F10, PS2_F8, PS2_F6, PS2_F4, PS2_TAB, '~', 0,
	0, 0 /*Lalt*/, 0 /*Lshift*/, 0, 0 /*Lctrl*/, 'Q', '!', 0,
	0, 0, 'Z', 'S', 'A', 'W', '@', 0,
	0, 'C', 'X', 'D', 'E', '$', '#', 0,
	0, ' ', 'V', 'F', 'T', 'R', '%', 0,
	0, 'N', 'B', 'H', 'G', 'Y', '^', 0,
	0, 0, 'M', 'J', 'U', '&', '*', 0,
	0, '<', 'K', 'I', 'O', ')', '(', 0,
	0, '>', '?', 'L', ':', 'P', '_', 0,
	0, 0, '"', 0, '{', '+', 0, 0,
	0 /*CapsLock*/, 0 /*Rshift*/, PS2_ENTER /*Enter*/, '}', 0, '|', 0, 0,
	0, 0, 0, 0, 0, 0, PS2_BACKSPACE, 0,
	0, '1', 0, '4', '7', 0, 0, 0,
	'0', '.', '2', '5', '6', '8', PS2_ESC, 0 /*NumLock*/,
	PS2_F11, '+', '3', '-', '*', '9', PS2_SCROLL, 0,
	0, 0, 0, PS2_F7 },
	0
};
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

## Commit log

2023-12-02 USB Keyboard
    [zx81_kbd v0.1.brd, zx81_kbd v0.1.sch, zx81_kbd v0.2.brd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]
2023-12-11 Initial public version
    [zx81_kbd v0.4.brd]

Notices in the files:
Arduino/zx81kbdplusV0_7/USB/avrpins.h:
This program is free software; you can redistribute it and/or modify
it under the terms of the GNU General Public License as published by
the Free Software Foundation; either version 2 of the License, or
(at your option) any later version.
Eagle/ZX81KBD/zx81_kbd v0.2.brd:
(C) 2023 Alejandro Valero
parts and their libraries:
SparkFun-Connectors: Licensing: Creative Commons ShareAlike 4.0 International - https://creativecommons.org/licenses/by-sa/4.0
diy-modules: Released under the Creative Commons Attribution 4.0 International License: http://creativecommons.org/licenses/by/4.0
